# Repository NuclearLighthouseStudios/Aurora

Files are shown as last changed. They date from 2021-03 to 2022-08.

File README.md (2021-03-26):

# Aurora Temporal Aliaser

These are the KiCAD schematics and board layout filed for my Aurora Temporal Aliaser.  
If you just want the Gerber files or a PDF of the schematic check out the releases tab for downloads.

This PCB should be easily manufacturable with most online PCB houses by just uploading the gerber files.

This board is designed to be used with my Switchboard Pedal IO PCB which you can find [here](https://github.com/NuclearLighthouseStudios/Switchboard).

## BOM

| Reference | Quantity | Value  | Description |
| :--- | ---: | -----: | :--- |
| C1 C2 | 2 | 100n | Ceramic disk capacitor |
| C3 C4 | 2 | 100n | WIMA MKS2 63V |
| C5 | 1 | 10n | WIMA MKS2 63V |
| C6 | 1 | 1µ | WIMA MKS2 50V |
| C7 | 1 | 47n | WIMA MKS2 63V |
| J1 | 1 | | Pin Header, 6 pins, 2.54mm spacing |
| J2 | 1 | | DC Barrel Jack with internal switch |
| Q1 | 1 | BC547B | 0.1A Ic, 45V Vce, Small Signal NPN Transistor, TO-92:TO-92_Wide |
| Q2 | 1 | J113 | N-JFET transistor, drain/source/gate |
| R1 R2 R9  | 3 | 1M | Metal film resistor 1%, DIN 0207 |
| R3 R8 R11 | 3 | 1k | Metal film resistor 1%, DIN 0207 |
| R4 | 1 | 10k | Metal film resistor 1%, DIN 0207 |
| R5 R6 R7  | 3 | 100k | Metal film resistor 1%, DIN 0207 |
| R10 | 1 | 47k | Metal film resistor 1%, DIN 0207 |
| R12 | 1 | 100 | Metal film resistor 1%, DIN 0207 |
| RV1 | 1 | 100k | Alps RK09K1130C94 Potentiometer |
| U1 | 1 | TL072  | Dual Low-Noise JFET-Input Operational Amplifiers, DIP-8/SOIC-8  |
| U2 | 1 | NE555P | Precision Timers, 555 compatible, PDIP-8 |
| | 2 | | 8 pin DIP socket for U1 and U2 |

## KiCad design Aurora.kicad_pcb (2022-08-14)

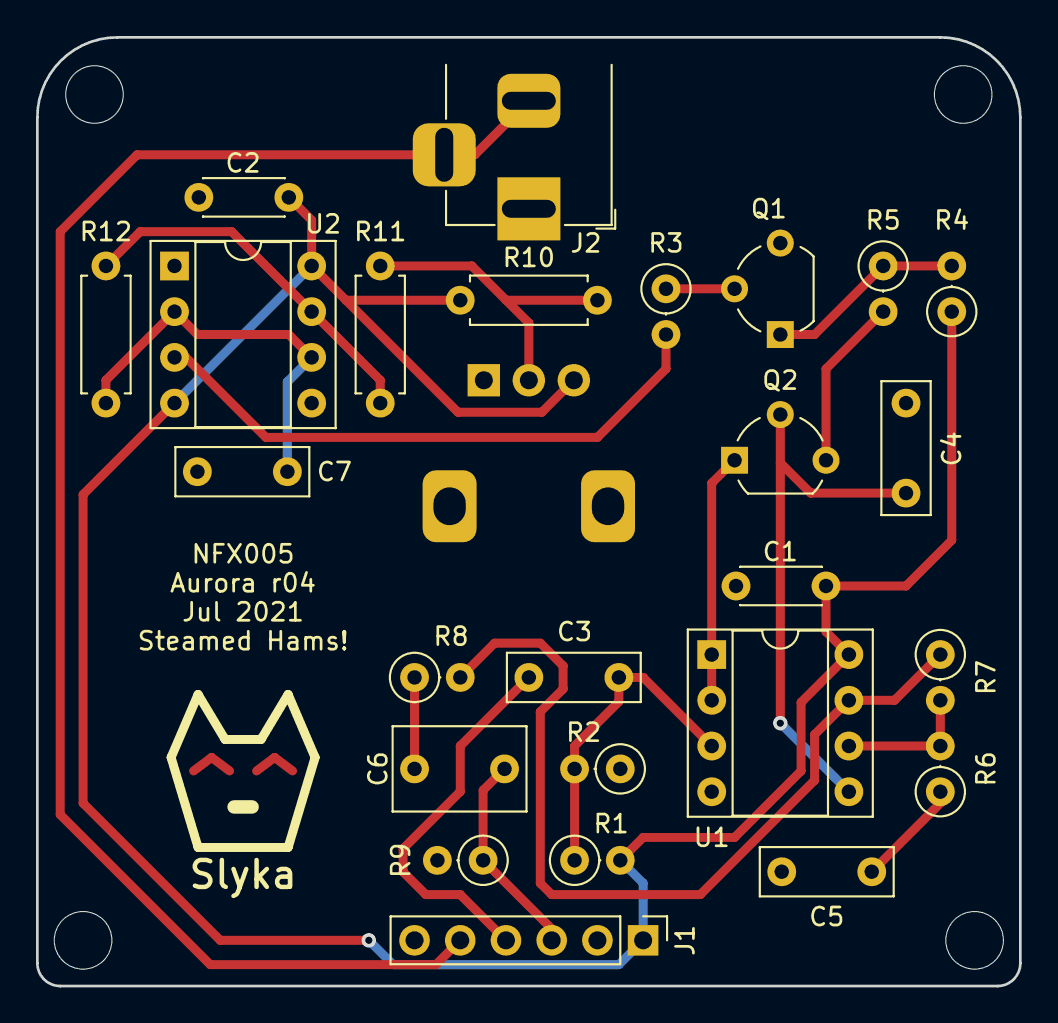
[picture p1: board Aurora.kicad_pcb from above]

Board: 2 copper layers, 54.6 x 52.7 mm, 26 parts (1 on the bottom side), 19 nets.

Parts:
C1, C2: 100n; C_Disc_D4.3mm_W1.9mm_P5.00mm
C3, C4: 100n; C_Rect_L7.2mm_W2.5mm_P5.00mm_FKS2_FKP2_MKS2_MKP2
C5: 10n; C_Rect_L7.2mm_W2.5mm_P5.00mm_FKS2_FKP2_MKS2_MKP2
C6: 1µ; C_Rect_L7.2mm_W4.5mm_P5.00mm_FKS2_FKP2_MKS2_MKP2
C7: 47n; C_Rect_L7.2mm_W2.5mm_P5.00mm_FKS2_FKP2_MKS2_MKP2
J1: Conn_01x06_Female; PinHeader_1x06_P2.54mm_Vertical
J2: Barrel_Jack_Switch; BarrelJack_Horizontal_Short
Q1: BC547; TO-92_Wide
Q2: J113; TO-92_Wide
R1, R2, R9: 1M; R_Axial_DIN0207_L6.3mm_D2.5mm_P2.54mm_Vertical
R3, R8: 1k; R_Axial_DIN0207_L6.3mm_D2.5mm_P2.54mm_Vertical
R4: 10k; R_Axial_DIN0207_L6.3mm_D2.5mm_P2.54mm_Vertical
R5, R6, R7: 100k; R_Axial_DIN0207_L6.3mm_D2.5mm_P2.54mm_Vertical
R10: 47k; R_Axial_DIN0207_L6.3mm_D2.5mm_P7.62mm_Horizontal
R11: 1k; R_Axial_DIN0207_L6.3mm_D2.5mm_P7.62mm_Horizontal
R12: 100; R_Axial_DIN0207_L6.3mm_D2.5mm_P7.62mm_Horizontal
RV1: 100k; Potentiometer_Alps_RK09K_Single_Vertical
U1: TL072; DIP-8_W7.62mm_Socket
U2: NE555P; DIP-8_W7.62mm_Socket

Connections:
+9V: J1.5, J2.2, J2.3
+9VA: C1.1, C2.1, J1.1, R1.2, R4.1, R10.1, RV1.3, U1.8 (V+), U2.4 (R), U2.8 (VCC)
Clock: R3.2, U2.3 (Q)
GND: C1.2, C2.2, C4.2, C5.2, C7.2, J1.6, J2.1, Q1.3 (E), R2.1, R9.2, U1.4 (V-), U2.1 (GND)
Input: C3.2, J1.4
unnamed: C3.1, R1.1, R2.2, U1.3 (+)
unnamed: C4.1, Q2.2 (S), U1.5 (+)
unnamed: C5.1, R6.1
unnamed: C6.2, R8.1
unnamed: C7.1, R12.1, U2.2 (TR), U2.6 (THR)
unnamed: Q1.1 (C), R4.2, R5.1
unnamed: Q1.2 (B), R3.1
unnamed: Q2.1 (D), U1.1, U1.2 (-)
unnamed: Q2.3 (G), R5.2
unnamed: R6.2, R7.2, U1.6 (-)
unnamed: R7.1, R8.2, U1.7
unnamed: R10.2, R11.2, RV1.2
unnamed: R11.1, R12.2, U2.7 (DIS)
Output: C6.1, J1.3, R9.1

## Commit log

2020-09-28 Initial commit! Whoo!
    [Aurora.kicad_pcb, Aurora.sch]
2020-10-04 Correctly annotate output DC reference resistor and add to PCB
    [Aurora.kicad_pcb, Aurora.sch]
2020-10-04 Bump revision
    [Aurora.kicad_pcb, Aurora.sch]
2020-11-16 Add readme with bom!
2020-11-16 Fix bom formatting
2020-12-31 Fix readme and bom
2020-12-31 Update BOM to latest board revision
2021-03-26 Include sockets for U1 and U2 in BOM
2021-07-04 Properly connect trace between R1 and R2
    [Aurora.kicad_pcb]
2022-08-14 Upgrade to KiCAD 6
    [Aurora.kicad_pcb, Aurora.kicad_sch, Aurora.sch]

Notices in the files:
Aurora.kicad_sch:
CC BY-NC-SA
